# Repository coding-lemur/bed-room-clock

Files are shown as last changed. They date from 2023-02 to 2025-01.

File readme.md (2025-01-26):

# Bedroom Clock with ESP32 ⏰

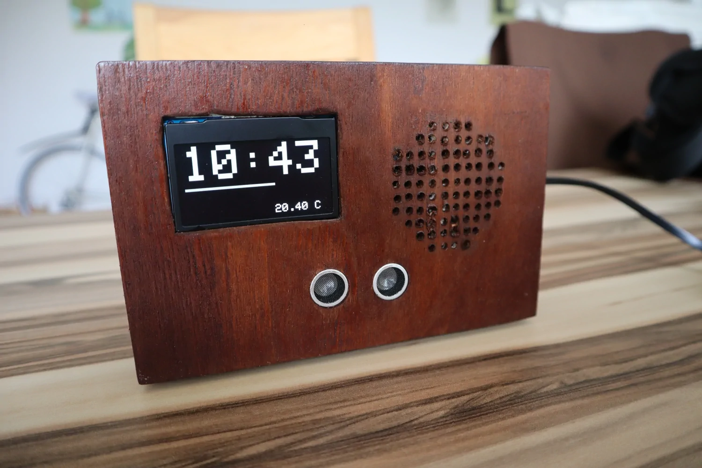
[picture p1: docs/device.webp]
final device


## Description

You can put this device in your bedroom and you won't be disturbed by the light of the display. The display is only activated when you move your hand in front of the device and then it automatically goes off again.

## Features

- OLED display
- display turn on if you move your hand in front of it
- temperature and humidity sensor
- easy integration in own WiFi network (Hotspot settings-page)
- [react dashboard](https://github.com/coding-lemur/bed-room-clock-dashboard)
- REST API endpoint
- OTA updates

## Demo

[See demo on Youtube](https://youtu.be/ncI8ftF5udI)

## Parts

- ESP32 DEV Board
- SSD1306 (I use a 2.42 inch version)
- HC-SR04
- DHT22
- MAX 98357A (audio module)
- speaker

## Sketch

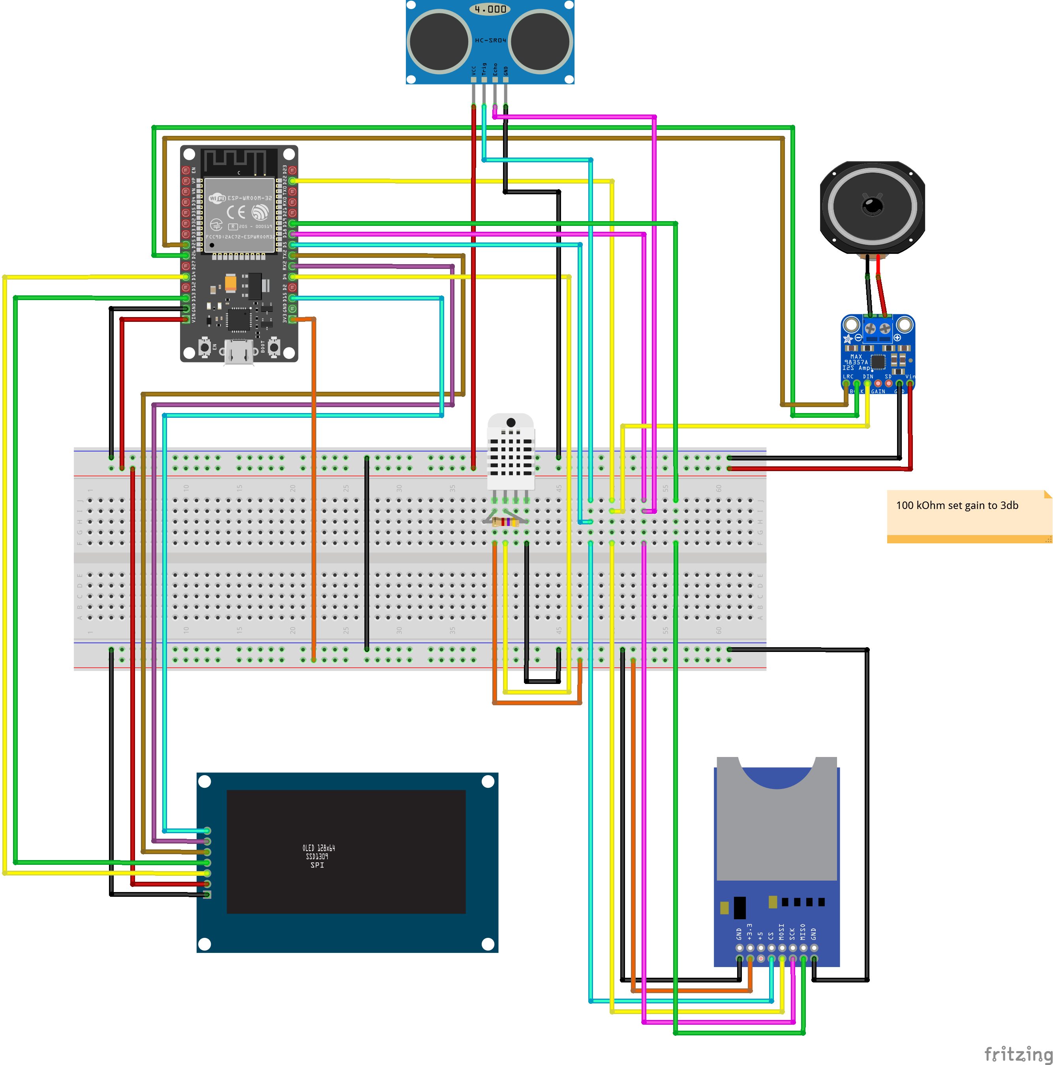
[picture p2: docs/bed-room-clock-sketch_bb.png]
sketch


## Wiring

### Ultra Sonic Sensor (HC-SR04)

| Pin on Sensor | Pin on ESP32 |
| --- | --- |
| VCC | VIN (5V) |
| TRIG | GPIO 5 |
| ECHO | GPIO 18 |
| GND | GND |

### OLED Display (SSD1306 128x64) via SPI

| Pin on Sensor | description | Pin on ESP32 |
| --- | --- | --- |
| GND | | GND |
| 5V | | VIN (5V) |
| SCK/SCL | SPI | GPIO 14 |
| MOSI/SDA | SPI | GPIO 13 |
| RES/RST | SPI | GPIO 17 |
| DC | SPI | GPIO 16 |
| CS | SPI | GPIO 15 |

### DHT22

| Pin on Sensor  | Pin on ESP32 |
| ---  | --- |
| 1 | 3V3 (3V) |
| 2 | GPIO 4 (analog) |
| 3 | - |
| 4 | GND |

### MAX 98357A (Audio Interface)

| Pin on Sensor  | Pin on ESP32 |
| ---  | --- |
| LRC | GPIO 25 |
| BCLK | GPIO 26 |
| DIN | GPIO 22 |
| GAIN | - |
| SD | - |
| GND | GND |
| Vin | Vin (5V) |

### SD Card Module

| Pin on Sensor | description | Pin on ESP32 |
| --- | --- | --- |
| GND | | GND |
| VCC | | 3V3 (3V) |
| MISO | SPI | GPIO 19 |
| MOSI/SDA | SPI | GPIO 23 |
| SCK/SCL | SPI | GPIO 18 |
| CS | SPI | GPIO 5 |

## Timezone configuration

First change variable `timeZone` to your timezone. See [timezone list](https://github.com/nayarsystems/posix_tz_db/blob/master/zones.csv) for the correct value.

Later I will include this setting also to the dashboard.

## REST API endpoint

### General

#### Get info

```http
GET /api/info
```

Returning an JSON object with following data:

| field | type | description |
| ---| -----| ---|
| version | string | firmware version number |
| ------| -----| ------------|
| system.deviceId | string | unique ID of the device |
| system.freeHeap | number | the free heap in bytes |
| system.uptime | number |  uptime since last restart of the device in seconds |
| ------| -----| ------------|
| fileSystem.totalBytes | number | total bytes of the FS |
| fileSystem.usedBytes | number | used bytes of the FS |
| ------| -----| ------------|
| network.wifiRssi | number | |
| network.wifiQuality | number | quality of the WiFi connection in percent  |
| network.wifiSsid | string | SSID of the current connected WiFi  |
| network.ip | string | IP address of the device  |
| network.mac | string | MAC address of the device  |
| ------| -----| ------------|
| values.temp | number | temperature in °C  |
| values.humidity | number | humidity in percent  |
| ------| -----| ------------|

#### Get settings

```http
GET /api/settings
```

Return the settings.json

#### Change settings

```http
POST /api/settings
```

Change settings.
Send payload as JSON in body.

| field | type | default | description |
| --- | --- | --- | --- |
| screenOnDistance | number (0 - 255) | 18 cm | Specifies the distance from the ultrasonic sensor in centimeters from when the display should be switched on. |
| screenOnInterval | number | 8000 ms | Specifies the time in milliseconds that the display stays on after motion detection. |

#### Turn on Screen

```http
POST /api/display
```

Turn on the display for the screenOnInterval time.

#### Restart device

```http
POST /api/restart
```

#### Factory reset

```http
POST /api/hard-reset
```

Reset device to factory settings.

**Warning**: all files (~settings) will removed from the device. Need setup for connecting to your WiFi.

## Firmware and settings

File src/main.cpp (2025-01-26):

#include <Arduino.h>
#include <SPI.h>
#include <Wire.h>
#include <SPIFFS.h>
#include <WiFi.h>

// sensors
#include <NewPing.h>
#include <DHT.h>

// display
#include <Adafruit_SSD1306.h>
#include <Adafruit_GFX.h>
#include <Adafruit_I2CDevice.h>

#include <WiFiSettings.h>
#include <ArduinoOTA.h>
#include <time.h>
#include <ArduinoJson.h>
#include <StreamUtils.h>

// webserver
#include <AsyncTCP.h>
#include <AsyncJson.h>
#include <ESPAsyncWebServer.h>

#include <ESPAsyncTunnel.h>
#include <ESPmDNS.h>

#include "boot_logo.h"
#include "tools.h"
#include "config.h"

const String version = "1.6.0";

NewPing sonar(GPIO_NUM_5, GPIO_NUM_18);
Adafruit_SSD1306 ssd1306(SCREEN_WIDTH, SCREEN_HEIGHT, OLED_MOSI, OLED_CLK, OLED_DC, OLED_RESET, OLED_CS);
DHT dht(DHT_PIN, DHT_TYPE);
AsyncWebServer server(80);

// TODO move to settings
const char *ntpServer = "pool.ntp.org";
const char *timeZone = "CET-1CEST,M3.5.0,M10.5.0/3";

// TODO move to settings
const char *externalBaseUrl = "https://coding-lemur.github.io";
const char *indexPath = "/bed-room-clock-dashboard/index.html";

bool isPortalActive = false;
float lastTemperature = -100;
float lastHumidity = -100;
bool isTimeColonVisible = true;

// settings
byte screenOnDistance = 18;                // in cm
unsigned long screenOnInterval = 8 * 1000; // in ms

unsigned long lastDisplayUpdate = 0;
unsigned long lastDhtUpdate = 0;
unsigned long lastDistanceUpdate = 0;
unsigned long lastScreenOn = 0;

void saveSettings()
{
  StaticJsonDocument<384> settings;
  settings["screenOnDistance"] = screenOnDistance;
  settings["screenOnInterval"] = screenOnInterval;

  File file = SPIFFS.open(SETTINGS_FILENAME, FILE_WRITE);

  if (serializeJson(settings, file) == 0)
  {
    Serial.println("error on writing 'settings.json'");
  }

  file.close();
}

void loadSettings()
{
  if (!SPIFFS.exists(SETTINGS_FILENAME))
  {
    saveSettings();
    return;
  }

  File file = SPIFFS.open(SETTINGS_FILENAME, FILE_READ);
  StaticJsonDocument<384> settings;
  auto error = deserializeJson(settings, file);
  file.close();

  if (error)
  {
    Serial.println("error on deserializing 'auto-starts' file: ");
    saveSettings();
    return;
  }

  bool hasMissingFields = false;

  if (settings.containsKey("screenOnDistance"))
  {
    screenOnDistance = settings["screenOnDistance"].as<byte>();
  }
  else
  {
    hasMissingFields = true;
  }

  if (settings.containsKey("screenOnInterval"))
  {
    screenOnInterval = settings["screenOnInterval"].as<unsigned long>();
  }
  else
  {
    hasMissingFields = true;
  }

  if (hasMissingFields)
  {
    saveSettings();
  }
}

StaticJsonDocument<512> getInfoJson()
{
  StaticJsonDocument<512> doc;
  doc["version"] = version;

  JsonObject systemPart = doc.createNestedObject("system");
  systemPart["deviceId"] = getDeviceId(WiFiSettings.hostname);
  systemPart["freeHeap"] = ESP.getFreeHeap();                // in bytes
  systemPart["uptime"] = esp_timer_get_time() / 1000 / 1000; // in seconds
  systemPart["time"] = getUnixTime();

  JsonObject fileSystemPart = doc.createNestedObject("fileSystem");
  fileSystemPart["totalBytes"] = SPIFFS.totalBytes();
  fileSystemPart["usedBytes"] = SPIFFS.usedBytes();

  JsonObject networkPart = doc.createNestedObject("network");
  int8_t rssi = WiFi.RSSI();
  networkPart["wifiRssi"] = rssi;
  networkPart["wifiQuality"] = getRssiAsQuality(rssi);
  networkPart["wifiSsid"] = WiFi.SSID();
  networkPart["ip"] = WiFi.localIP().toString();
  networkPart["mac"] = WiFi.macAddress();

  /*JsonObject playerPart = doc.createNestedObject("player");
  playerPart["isPlaying"] = audio.isRunning();
  playerPart["codec"] = audio.getCodecname();
  playerPart["bitrate"] = audio.getBitRate();
  playerPart["volume"] = audio.getVolume();*/

  JsonObject valuesPart = doc.createNestedObject("values");

  if (lastTemperature > -100)
  {
    valuesPart["temp"] = round2(lastTemperature);
  }

  if (lastHumidity > -100)
  {
    valuesPart["humidity"] = round2(lastHumidity);
  }

  return doc;
}

void onChangeSettings(AsyncWebServerRequest *request, JsonVariant &json)
{
  StaticJsonDocument<200> data = json.as<JsonObject>();

  bool isDirty = false;

  if (data.containsKey("screenOnDistance"))
  {
    screenOnDistance = data["screenOnDistance"].as<byte>();
    isDirty = true;
  }

  if (data.containsKey("screenOnInterval"))
  {
    screenOnInterval = data["screenOnInterval"].as<unsigned long>();
    isDirty = true;
  }

  if (isDirty)
  {
    saveSettings();
    request->send(200);
    return;
  }

  request->send(400); // bad request
}

void setupWebserver()
{
  // rewrites
  server.rewrite("/", indexPath);
  server.rewrite("/index.html", indexPath);
  server.rewrite("/favicon.ico", "/bed-room-clock-dashboard/favicon.ico");

  // tunnel the index.html request
  server.on(indexPath, HTTP_GET, [&](AsyncWebServerRequest *request)
            {
      ClientRequestTunnel tunnel;
      if (tunnel.open(externalBaseUrl, request->url())) {
          String result = tunnel.getString();
          request->send(200, "text/html", result);
      } else {
          request->send(tunnel.getHttpCode());
      } });

  server.on("/bed-room-clock-dashboard/*", HTTP_GET, [&](AsyncWebServerRequest *request)
            {
    String moved_url = externalBaseUrl+request->url();
    request->redirect(moved_url); });

  server.on("/api/info", HTTP_GET, [](AsyncWebServerRequest *request)
            {
        StringStream stream;
        auto size = serializeJson(getInfoJson(), stream);

        request->send(stream, "application/json", size); });

  server.on("/api/settings", HTTP_GET, [](AsyncWebServerRequest *request)
            { request->send(SPIFFS, SETTINGS_FILENAME, "application/json", false); });

  server.on("/api/display", HTTP_POST, [](AsyncWebServerRequest *request)
            {
              lastScreenOn = millis(); // turn on screen
              request->send(200); });

  server.on("/api/hard-reset", HTTP_POST, [](AsyncWebServerRequest *request)
            {
    request->send(200);

    SPIFFS.format();
    delay(1000);
    ESP.restart(); });

  server.on("/api/restart", HTTP_POST, [](AsyncWebServerRequest *request)
            {
              request->send(200);

              delay(1000);
              ESP.restart(); });

  server.addHandler(new AsyncCallbackJsonWebHandler("/api/settings", onChangeSettings));

  server.begin();
}

// Start ArduinoOTA via WiFiSettings with the same hostname and password
void setupOta()
{
  ArduinoOTA.setHostname(WiFiSettings.hostname.c_str());
  ArduinoOTA.setPassword(WiFiSettings.password.c_str());
  ArduinoOTA.begin();
}

void setupDisplay()
{
  if (!ssd1306.begin(SSD1306_SWITCHCAPVCC))
  {
    Serial.println(F("SSD1306 allocation failed"));
    for (;;)
      ; // Don't proceed, loop forever
  }

  delay(1000);

  ssd1306.setRotation(2); // flip screen
  ssd1306.clearDisplay();

  ssd1306.drawBitmap(0, 0, bootLogo, 128, 64, WHITE);
  ssd1306.display();
  delay(2000);

  ssd1306.clearDisplay();
  ssd1306.setTextColor(WHITE);
  ssd1306.setTextSize(1);

  ssd1306.setCursor(0, 0);
  ssd1306.print(">> BedRoom Clock <<");

  ssd1306.setCursor(0, 10);
  ssd1306.print(version);

  ssd1306.display();
  delay(2000);

  // turn on screen
  lastScreenOn = millis();
}

void setupMDns()
{
  if (!MDNS.begin("bedroom-clock"))
  {
    Serial.println("Error starting mDNS");
  }

  MDNS.addService("http", "tcp", 80);
}

void WiFiStationDisconnected(WiFiEvent_t event, WiFiEventInfo_t info)
{
  WiFi.reconnect();
}

void setupWifiSettings()
{
  WiFi.onEvent(WiFiStationDisconnected, WiFiEvent_t::ARDUINO_EVENT_WIFI_STA_DISCONNECTED);

  WiFiSettings.secure = true;
  WiFiSettings.hostname = "bedroom-"; // will auto add device ID
  WiFiSettings.password = PASSWORD;

  // Set callbacks to start OTA when the portal is active
  WiFiSettings.onPortal = []()
  {
    isPortalActive = true;

    Serial.println("WiFi config portal active");

    setupOta();

    ssd1306.clearDisplay();
    ssd1306.setTextSize(1);

    ssd1306.setCursor(0, 0);
    ssd1306.print("connect to WiFi and");

    ssd1306.setCursor(0, 10);
    ssd1306.print("setup the device");

    ssd1306.setCursor(0, 30);
    ssd1306.print(WiFiSettings.hostname);

    ssd1306.setCursor(0, 40);
    ssd1306.print("password:");
    ssd1306.print(PASSWORD);

    ssd1306.display();
  };
  WiFiSettings.onPortalWaitLoop = []()
  {
    ArduinoOTA.handle();
  };
  WiFiSettings.onConfigSaved = []()
  {
    ESP.restart();
  };
  WiFiSettings.onConnect = []()
  {
    ssd1306.clearDisplay();
    ssd1306.setTextSize(1);

    ssd1306.setCursor(0, 0);
    ssd1306.print("connecting to WiFi...");

    ssd1306.setCursor(0, 10);
    ssd1306.print(WiFi.SSID());

    ssd1306.display();
  };
  WiFiSettings.onSuccess = []()
  {
    ssd1306.clearDisplay();
    ssd1306.setTextSize(1);

    ssd1306.setCursor(0, 0);
    ssd1306.print("WiFi connected");

    ssd1306.setCursor(0, 10);
    ssd1306.print(WiFi.SSID());

    ssd1306.display();
  };
  WiFiSettings.onFailure = []()
  {
    ssd1306.clearDisplay();
    ssd1306.setTextSize(1);

    ssd1306.setCursor(0, 0);
    ssd1306.print("WiFi error ");

    ssd1306.setCursor(0, 10);
    ssd1306.print(WiFi.SSID());

    ssd1306.display();
  };

  // Use stored credentials to connect to your WiFi access point.
  // If no credentials are stored or if the access point is out of reach,
  // an access point will be started with a captive portal to configure WiFi.
  WiFiSettings.connect();
}

void setup()
{
  Serial.begin(115200);
  Wire.begin();

  SPIFFS.begin(true); // Will format on the first run after failing to mount
  // SPIFFS.format();    // TODO reset config on connection MQTT fail

  loadSettings();

  setupDisplay();
  setupWifiSettings();
  setupMDns();
  setupWebserver();
  setupOta();
  configTzTime(timeZone, ntpServer);
  dht.begin();
}

void loop()
{
  ArduinoOTA.handle(); // If you also want the OTA during regular execution

  if (isPortalActive)
  {
    return;
  }

  bool shouldUpdateDhtValues = millis() - lastDhtUpdate >= DHT_UPDATE_INTERVAL;

  if (shouldUpdateDhtValues)
  {
    // wait a two seconds between measurements
    lastTemperature = dht.readTemperature();
    lastHumidity = dht.readHumidity();

    lastDhtUpdate = millis();
  }

  unsigned long lastDistance = sonar.ping_cm();
  if (lastDistance > 0 && lastDistance <= screenOnDistance)
  {
    // turn on display
    lastScreenOn = millis();
  }

  bool isDisplayOff = millis() - lastScreenOn >= screenOnInterval;
  bool shouldUpdateScreen = millis() - lastDisplayUpdate >= SCREEN_UPDATE_INTERVAL;

  // turn on/off screen
  uint8_t command = isDisplayOff ? SSD1306_DISPLAYOFF : SSD1306_DISPLAYON;
  ssd1306.ssd1306_command(command);

  if (!isDisplayOff && shouldUpdateScreen)
  {
    struct tm timeinfo;
    if (!getLocalTime(&timeinfo))
    {
      // TODO show error on display
      Serial.println("Failed to obtain time");
      return;
    }

    ssd1306.clearDisplay();

    // show time
    ssd1306.setTextSize(4);
    ssd1306.setCursor(3, 0);
    ssd1306.print(&timeinfo, "%H");

    ssd1306.print(isTimeColonVisible ? ":" : " ");
    isTimeColonVisible = !isTimeColonVisible;

    ssd1306.print(&timeinfo, "%M");
    /*ssd1306.print(":");
    ssd1306.print(&timeinfo, "%S");*/

    // show progressbar (for seconds value)
    int16_t pixel = (120 * timeinfo.tm_sec) / 60;
    ssd1306.fillRect(3, 35, pixel, 2, SSD1306_INVERSE);

    if (lastTemperature > -100)
    {
      // show temperature
      ssd1306.setTextSize(1);
      ssd1306.setCursor(ssd1306.width() - 50, ssd1306.height() - 10);
      ssd1306.print(lastTemperature);
      ssd1306.print(" C");
    }

    ssd1306.display();

    lastDisplayUpdate = millis();
  }
}

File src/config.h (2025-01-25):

#define PASSWORD "sleeeping"

#define SCREEN_WIDTH 128            // OLED display width, in pixels
#define SCREEN_HEIGHT 64            // OLED display height, in pixels
#define SCREEN_UPDATE_INTERVAL 1000 // in milliseconds

#define OLED_MOSI 13
#define OLED_CLK 14
#define OLED_DC 16
#define OLED_CS 15
#define OLED_RESET 17

#define DHT_PIN 4
#define DHT_TYPE DHT22                // DHT 22  (AM2302), AM2321
#define DHT_UPDATE_INTERVAL 20 * 1000 // in milliseconds

#define SETTINGS_FILENAME "/settings.json"

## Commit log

2022-04-22 add sketch
    [beed-room-clock Sketch.fzz]
2022-05-19 change OLED to SPI interface
2022-05-19 fix linebreak in time
    [main.cpp]
2022-05-19 correct ultrasonic sensor trigger pin
2022-05-19 switch to DHT library from Adafruit
2022-05-19 flip screen; change display layout; move update intervalls to config
    [config.h, main.cpp]
2022-06-15 add picture of the final device
2022-06-16 Renaming files
    without any space
    [beed-room-clock-sketch.fzz]
2022-06-29 replace display with SPI version
    [beed-room-clock-sketch.fzz]
2022-07-03 only put sensor data into JSON if they have values; remove debug output
2022-07-03 fix code naming conventions
    [main.cpp]
2022-07-05 change ultrasonic lib to NewPing; fix update distance; optimize code
    [main.cpp]
2022-07-10 fix WiFi reconnection; add uptime to info API endpoint; show status on screen (for setup, wifi connection)
    [main.cpp]
2022-09-22 Feat/brightness (#5)
    * add mDNS
    * use external portal to show sensor and generic device values
    * change brightness via portal
    * add hard-reset endpoint
    * remove unused library
    * add current time to info endpoint
    * optimize status messages
    [main.cpp]
2022-09-23 format internal storage on hard-reset; remove unused code; update readme
    [main.cpp]
2022-09-25 Feat/dynamic settings (#6)
    * move SCREEN_ON_DISTANCE to dynamic settings; optimize code
    * move screenOnInterval to dynamic settings
    * Update readme.md
    * optimize logic for loading and saving settings; add TODOs
    * fix some settings erros; move SETTINGS_FILENAME to static config
    * fix saving default settings if file not existis to load fields in dashboard
    * fix add missing settings fields
    * add boot logo; fix showing version after boot
    [config.h, main.cpp]
2023-02-13 Feat/audio (#7)
    * change sketch
    * change sketch
    * add audio libs
    * auto change settings
    * extend flash size
    * change version number
    * update libraries
    * remove AsyncElegantOTA
    * change partition
    * separate configs for OTA and COM upload; update libraries
    * fix missing external libraries on build
    * stop autoplay of stream; add TODOs
    * add API endpoints for player
    * fix typing
    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
    [beed-room-clock-sketch.fzz]
2023-02-14 remove note
    [beed-room-clock-sketch.fzz]
2023-09-24 remove brightness setting because it not working
    [main.cpp]
2023-10-29 fix filenames
    [bed-room-clock-sketch.fzz, beed-room-clock-sketch.fzz]
2023-10-29 update sketch
    [bed-room-clock-sketch.fzz]
